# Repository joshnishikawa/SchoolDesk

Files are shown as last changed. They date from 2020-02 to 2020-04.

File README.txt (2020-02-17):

***************************************************************
     School Desk
a plug-and-play velocity-sensitive USB MIDI drum controller
***************************************************************

NOTE: School Desk is a controller. It is not a sequencer or synthesizer,
      nor is there a sound bank of any kind. It only sends MIDI messages
      to trigger sounds in a Digital Audio Workstation (DAW).
      You must have your DAW open and have School Desk assigned to control an
      instrument with its own soundbank or synthesis in the DAW.
     
Plug your School Desk into a USB port and it will be automatically recognized
as a MIDI controller and should appear as "SchoolDesk" in your DAW.

School Desk has two banks which store 11 sounds each.

These are the default sounds for Bank 1:
 __________ __________ __________ __________ __________ __________
|1         |2         |3         |4         |5         |6         |
| Crash 1  | Hi Tom   | Low Tom  | Splash   | Ride Bell| Crash 2  |
| Note #49 | Note #50 | Note #45 | Note #55 | Note #53 | Note #57 |
'----------^----------^----------^----------^----------^----------'
|7           |8           |9            |10          |11          |
| Snare Drum |  Hi-Hats   |  Floor Tom  | Ride Cymbal| Kick Drum  |
| Note #38   |  Note #46  |  Note #41   | Note #51   | Note #36   |
'------------^------------^-------------^------------^------------'

These are the default sounds for Bank 2:
 __________ __________ __________ __________ __________ __________
|1         |2         |3         |4         |5         |6         |
| Hi Timb. | Hi Bongo | Hi Conga | Cowbell  | Mute Tri.|Tambourine|
| Note #65 | Note #60 | Note #63 | Note #56 | Note #80 | Note #54 |
'----------^----------^----------^----------^----------^----------'
|7           |8           |9            |10          |11          |
| Low Timbale| Low Bongo  | Low Conga   | Triangle   | Claves     |
| Note #66   | Note #61   | Note #64    | Note #81   | Note #75   |
'------------^------------^-------------^------------^------------'

You can switch between banks 1 and 2 by quickly pressing and releasing
The "Edit" button.

--------------------------------------------------------------------------------

Different sounds can also be assigned to each pad by following these steps:

1. Press and HOLD the Edit knob on top of the controller for one second.
    (The red LED blinks when the knob is pressed and stays lit after one second)
    
2. Release the knob. The controller is now in "Program Mode" where pads can be
    assigned different sounds or be set as expression controllers.

3. While in program mode - indicated by the red LED - trigger the pad you want
    to change. The assigned sound will play (or no sound if set as expression
    controller).

4. Turn the knob until you reach the desired sound.* Turning the knob will
    reassign an expression controller as a drum sound. To assign the pad as an
    expression controller, briefly press and release the knob the same way you
    would to change between banks A and B.
    
5. When you have finished choosing your sounds. Press and hold the Edit knob
    for one second again. The LED will return to green or blue (depending on the
    bank).  The sounds you selected will be saved to internal memory and will be
    available the next time you plug in School Desk (unltil you change them).
    
    *NOTE: Turning the knob will cycle though note numbers 35 through 81.
          These are the numbers that are assigned to drum sounds according to
          the general MIDI standard. These numbers are as follows:

               GM DRUM SOUNDS
          *********************************
          MIDI# - NOTE - SOUND
            35    B  0   Acoustic Bass Drum
            36    C  1   Bass Drum 1
            37    C# 1   Side Stick
            38    D  1   Acoustic Snare
            39    D# 1   Hand Clap
            40    E  1   Electric Snare
            41    F  1   Low Floor Tom
            42    F# 1   Closed Hi Hat
            43    G  1   High Floor Tom
            44    G# 1   Pedal Hi-Hat
            45    A  1   Low Tom
            46    A# 1   Open Hi-Hat
            47    B  1   Low-Mid Tom
            48    C  2   Hi-Mid Tom
            49    C# 2   Crash Cymbal 1
            50    D  2   High Tom
            51    D# 2   Ride Cymbal 1
            52    E  2   Chinese Cymbal
            53    F  2   Ride Bell
            54    F# 2   Tambourine
            55    G  2   Splash Cymbal
            56    G# 2   Cowbell
            57    A  2   Crash Cymbal 2
            58    A# 2   Vibraslap
            59    B  2   Ride Cymbal 2
            60    C  3   Hi Bongo
            61    C# 3   Low Bongo
            62    D  3   Mute Hi Conga
            63    D# 3   Open Hi Conga
            64    E  3   Low Conga
            65    F  3   High Timbale
            66    F# 3   Low Timbale
            67    G  3   High Agogo
            68    G# 3   Low Agogo
            69    A  3   Cabasa
            70    A# 3   Maracas
            71    B  3   Short Whistle
            72    C  4   Long Whistle
            73    C# 4   Short Guiro
            74    D  4   Long Guiro
            75    D# 4   Claves
            76    E  4   Hi Wood Block
            77    F  4   Low Wood Block
            78    F# 4   Mute Cuica
            79    G  4   Open Cuica
            80    G# 4   Mute Triangle
            81    A  4   Open Triangle

    Any note which does not have a sound assigned to it in your DAW
    will not be audible.

--------------------------------------------------------------------------------

You may also set any (or all) of the pads to be used as expression controllers.

These are the Control Change numbers used for Bank 1:
 __________ __________ __________ __________ __________ __________
|1         |2         |3         |4         |5         |6         |
|          |          |          |          |          |          |
|  CC #20  |  CC #21  |  CC #22  |  CC #23  |  CC #24  |  CC #25  |
'----------^----------^----------^----------^----------^----------'
|7           |8           |9            |10          |11          |
|            |            |             |            |            |
|   CC #26   |   CC #27   |   CC #28    |   CC #29   |   CC #30   |
'------------^------------^-------------^------------^------------'

These are the Control Change numbers used for Bank 2:
 __________ __________ __________ __________ __________ __________
|1         |2         |3         |4         |5         |6         |
|          |          |          |          |          |          |
|  CC #102 |  CC #103 |  CC #104 |  CC #105 |  CC #106 |  CC #107 |
'----------^----------^----------^----------^----------^----------'
|7           |8           |9            |10          |11          |
|            |            |             |            |            |
|   CC #108  |   CC #109  |   CC #110   |   CC #111  |   CC #112  |
'------------^------------^-------------^------------^------------'

NOTE: All of these Control Change numbers are otherwise 'undefined' in the
      general MIDI specification and should therefore be safe to use.
      However, please be aware that these numbers cannot be changed.

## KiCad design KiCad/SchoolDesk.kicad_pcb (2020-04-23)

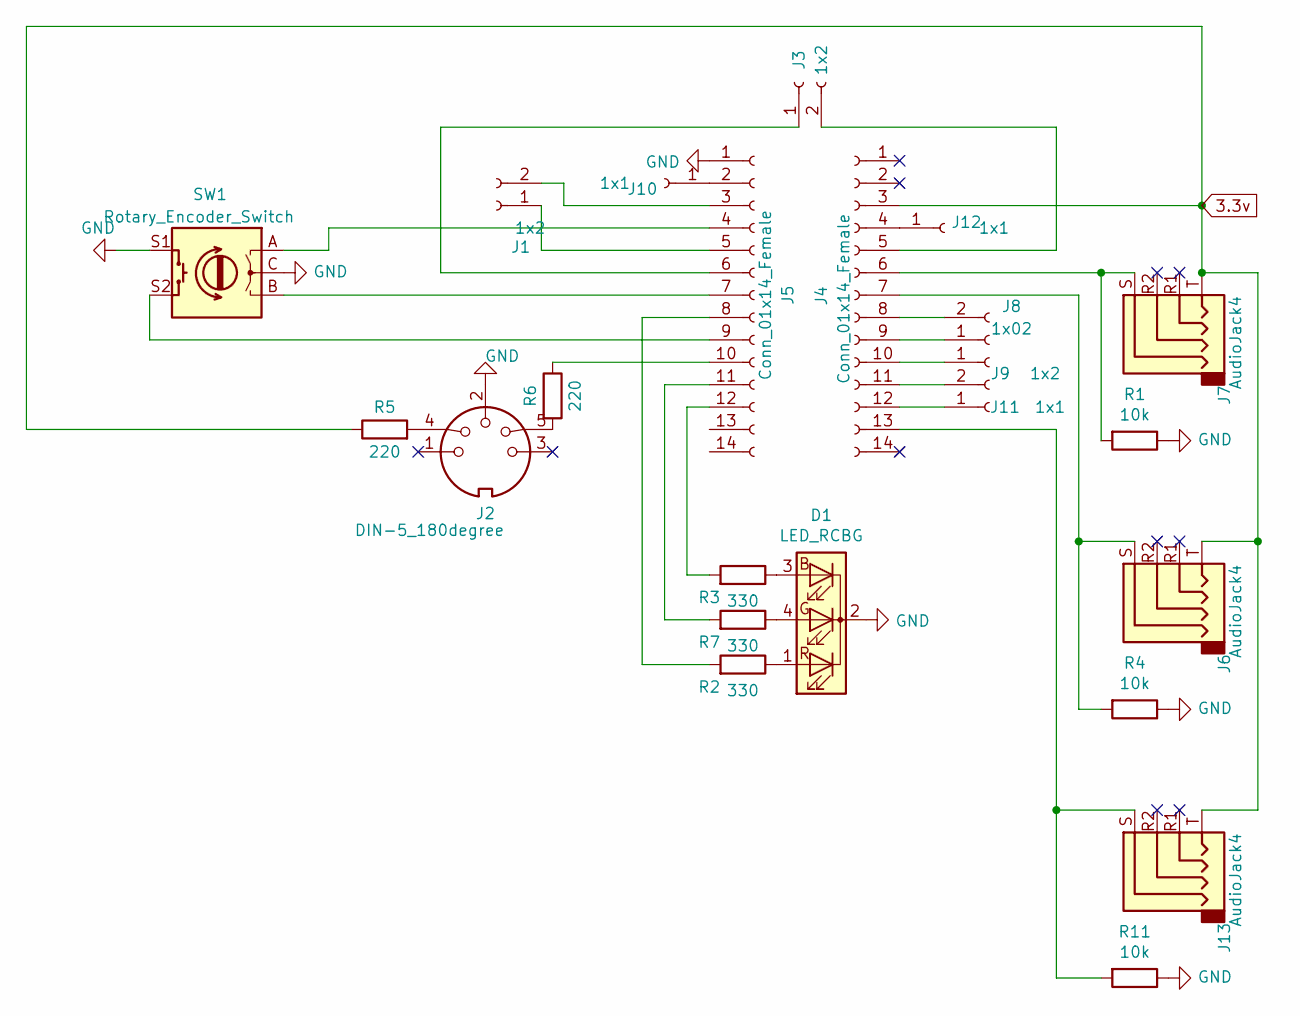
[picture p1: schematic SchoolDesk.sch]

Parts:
D1: LED_RCBG; LED_RGB_1210
J1, J3, J9: 1x2; Pin_Header_Straight_1x02_Pitch2.00mm
J2: DIN-5_180degree; SDS-50J
J4, J5: Conn_01x14_Female; PinSocket_1x14_P2.54mm_Vertical
J6, J7, J13: AudioJack4; Jack_3.5mm_PJ320D_Horizontal
J8: 1x02; Pin_Header_Straight_1x02_Pitch2.00mm
J10, J11, J12: 1x1; Pin_Header_Straight_1x01_Pitch2.00mm
R1, R4, R11: 10k; R_Axial_DIN0207_L6.3mm_D2.5mm_P2.54mm_Vertical
R2, R3, R7: 330; R_0805_2012Metric
R5, R6: 220; R_0805_2012Metric
SW1: Rotary_Encoder_Switch; Rotary_Encoder_Switched_PEC11R

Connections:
3.3v: J4.3, J6.T, J7.T, J13.T, R5.1
GND: D1.2 (K), J2.2, J5.1, R1.1, R4.1, R11.1, SW1.C, SW1.S1
unnamed: D1.1 (RA), R2.1
unnamed: D1.3 (BA), R3.1
unnamed: D1.4 (GA), R7.1
unnamed: J1.1, J5.5
unnamed: J1.2, J5.3
unnamed: J2.4, R5.2
unnamed: J2.5, R6.2
unnamed: J3.1, J5.6
unnamed: J3.2, J4.5
unnamed: J4.6, J7.S, R1.2
unnamed: J4.7, J6.S, R4.2
unnamed: J4.8, J8.2
unnamed: J4.9, J8.1
unnamed: J4.10, J9.1
unnamed: J4.11, J9.2
unnamed: J5.4, SW1.A
unnamed: J5.7, SW1.B
unnamed: J5.8, R2.2
unnamed: J5.9, SW1.S2
unnamed: J5.10, R6.1
unnamed: J5.11, R7.2
unnamed: J5.12, R3.2
unnamed: J5.2, J10.1
unnamed: J4.12, J11.1
unnamed: J4.4, J12.1
unnamed: J4.13, J13.S, R11.2

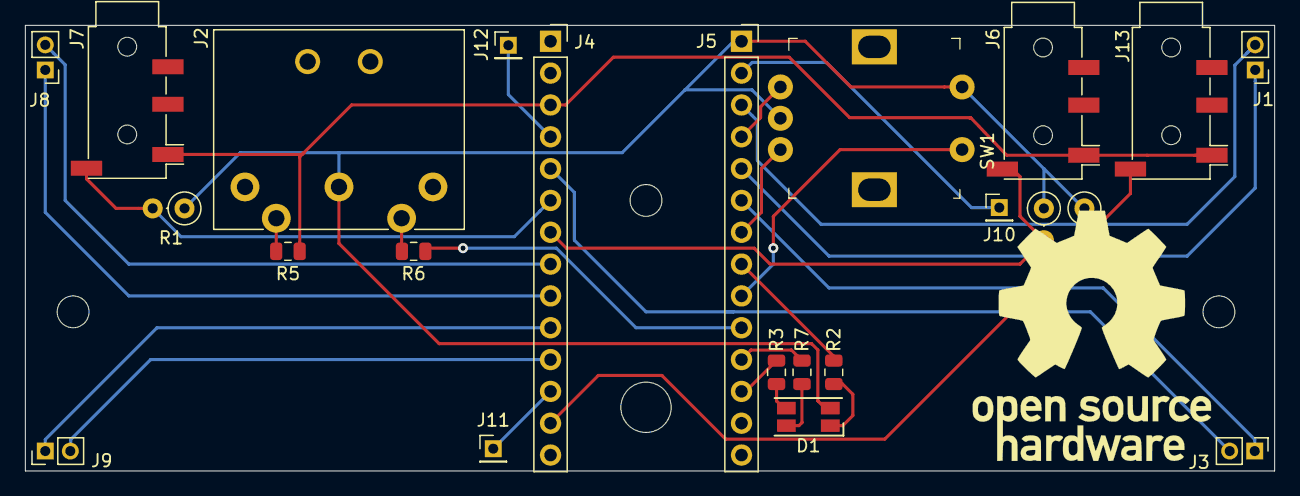
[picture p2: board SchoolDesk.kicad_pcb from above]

Board: 2 copper layers, 99.7 x 35.6 mm, 23 parts (0 on the bottom side), 28 nets.

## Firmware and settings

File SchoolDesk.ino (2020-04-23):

#include "SchoolDesk.h"

MIDI_CREATE_DEFAULT_INSTANCE();
MIDI_CREATE_INSTANCE(HardwareSerial, Serial3, MIDI1);
MIDI_CREATE_INSTANCE(HardwareSerial, Serial3, MIDI2);
MIDI_CREATE_INSTANCE(HardwareSerial, Serial3, MIDI3);

byte MIDIchannel = 10;
const int redLED = 9;
const int greenLED = 6;
const int blueLED = 10;
Editor editor = Editor(2, 5, 7);
int editMe = 255;
MIDIdrum *Drum[22]; // Drum sounds for banks A and B
MIDItouch *Exp[22]; // Exp controllers for banks A and B
bool useExp[22];    // Use Exp instead of Drum?
int bankIndex = 0;  // 0 = bank A, 11 = bank B, 
bool programMode = false;
elapsedMillis timer = 0;   // > 1000 = toggles program mode

elapsedMillis stayLit = 0; // for the metronome LED
int pulse = 0;
void onStart(){pulse = 0;}
void onContinue(){pulse = 0;}
void onStop(){pulse = 0;}

void onClock() {
  pulse = pulse == 24 ? 0 : pulse;
  if(pulse == 0){
    stayLit = 0;
    digitalWrite(LED_BUILTIN, HIGH);
  }
  pulse += 1;
}

void pulsar(){
  static int value = 0;
  static bool reverse = false;
  static elapsedMillis tempo = 0;
  int reading = Exp[editMe]->read();

  value = reading >= 0 ? reading : value;
  if (tempo >= 255 - value*2) {
    reverse = !reverse;
    tempo = 0;
  }
  analogWrite(10, reverse ? tempo*1 : 255-tempo);
}


void setup(){
  Serial.begin(9600);
  delay(1000);
  Serial.println("firstofall");
  
//  EEPROM.put(127, 255); // WARNING! RESTORES DEFAULT SETTINGS!
  byte resetDefaults = EEPROM.read(127);

  for(int i=22;i<44;i++){
    if(resetDefaults){
      useExp[i] = EEPROM.put(i, false); // Defalut to using drums only
    }
    else{useExp[i] = EEPROM.read(i);    // or load user-saved settings
    }
  }
  Serial.println("andthen");

  Drum[0]  = new MIDIdrum(19, resetDefaults ? EEPROM.put(0, 49) : EEPROM.read(0), TOUCH);
  Drum[1]  = new MIDIdrum(18, resetDefaults ? EEPROM.put(1, 50) : EEPROM.read(1), TOUCH);
  Drum[2]  = new MIDIdrum(23, resetDefaults ? EEPROM.put(2, 45) : EEPROM.read(2), TOUCH);
  Drum[3]  = new MIDIdrum( 0, resetDefaults ? EEPROM.put(3, 55) : EEPROM.read(3), TOUCH);
  Drum[4]  = new MIDIdrum( 3, resetDefaults ? EEPROM.put(4, 53) : EEPROM.read(4), TOUCH);
  Drum[5]  = new MIDIdrum( 1, resetDefaults ? EEPROM.put(5, 57) : EEPROM.read(5), TOUCH);
  Drum[6]  = new MIDIdrum(17, resetDefaults ? EEPROM.put(6, 38) : EEPROM.read(6), TOUCH);
  Drum[7]  = new MIDIdrum(16, resetDefaults ? EEPROM.put(7, 46) : EEPROM.read(7), TOUCH);
  Drum[8]  = new MIDIdrum(15, resetDefaults ? EEPROM.put(8, 41) : EEPROM.read(8), TOUCH);
  Drum[9]  = new MIDIdrum(22, resetDefaults ? EEPROM.put(9, 51) : EEPROM.read(9), TOUCH);
  Drum[10] = new MIDIdrum( 4, resetDefaults ? EEPROM.put(10,36) : EEPROM.read(10),TOUCH);

  Drum[11] = new MIDIdrum(19, resetDefaults ? EEPROM.put(11, 65) : EEPROM.read(11), TOUCH);
  Drum[12] = new MIDIdrum(18, resetDefaults ? EEPROM.put(12, 60) : EEPROM.read(12), TOUCH);
  Drum[13] = new MIDIdrum(23, resetDefaults ? EEPROM.put(13, 63) : EEPROM.read(13), TOUCH);
  Drum[14] = new MIDIdrum( 0, resetDefaults ? EEPROM.put(14, 56) : EEPROM.read(14), TOUCH);
  Drum[15] = new MIDIdrum( 3, resetDefaults ? EEPROM.put(15, 80) : EEPROM.read(15), TOUCH);
  Drum[16] = new MIDIdrum( 1, resetDefaults ? EEPROM.put(16, 54) : EEPROM.read(16), TOUCH);
  Drum[17] = new MIDIdrum(17, resetDefaults ? EEPROM.put(17, 66) : EEPROM.read(17), TOUCH);
  Drum[18] = new MIDIdrum(16, resetDefaults ? EEPROM.put(18, 61) : EEPROM.read(18), TOUCH);
  Drum[19] = new MIDIdrum(15, resetDefaults ? EEPROM.put(19, 64) : EEPROM.read(19), TOUCH);
  Drum[20] = new MIDIdrum(22, resetDefaults ? EEPROM.put(20, 81) : EEPROM.read(20), TOUCH);
  Drum[21] = new MIDIdrum( 4, resetDefaults ? EEPROM.put(21, 75) : EEPROM.read(21), TOUCH);
  Serial.println("thenwhat");

  EEPROM.put(127, 0); // Allow user settings to be saved

/*  Exp[0]  = new MIDItouch(19, 20);
  Exp[1]  = new MIDItouch(18, 21);
  Exp[2]  = new MIDItouch(23, 22);
  Serial.println("boutta");
  Exp[3]  = new MIDItouch( 0, 23);
  Exp[4]  = new MIDItouch( 3, 24);
  Exp[5]  = new MIDItouch( 1, 25);
  Exp[6]  = new MIDItouch(17, 26);
  Exp[7]  = new MIDItouch(16, 27);
  Exp[8]  = new MIDItouch(15, 28);
  Exp[9]  = new MIDItouch(22, 29);
  Exp[10] = new MIDItouch( 4, 30);

  Exp[11] = new MIDItouch(19, 102);
  Exp[12] = new MIDItouch(18, 103);
  Exp[13] = new MIDItouch(23, 104);
  Exp[14] = new MIDItouch( 0, 105);
  Exp[15] = new MIDItouch( 3, 106);
  Exp[16] = new MIDItouch( 1, 107);
  Exp[17] = new MIDItouch(17, 108);
  Exp[18] = new MIDItouch(16, 109);
  Exp[19] = new MIDItouch(15, 110);
  Exp[20] = new MIDItouch(22, 111);
  Exp[21] = new MIDItouch( 4, 112);
*/
  for(int i=0;i<22;i++){ // calibrate all drums and exp controllers
    Drum[i]->setThreshold();
//    Exp[i]->inputRange();
  }
  Serial.println("dunnit");

  pinMode(greenLED, OUTPUT);
  pinMode(redLED, OUTPUT);
  pinMode(blueLED, OUTPUT);
  pinMode(LED_BUILTIN, OUTPUT); // orangeLED

  MIDI1.begin(MIDI_CHANNEL_OMNI); //MIDI1 MIDI2 and MIDI3 only need to send
  MIDI2.begin(MIDI_CHANNEL_OMNI); //no need to read each one
  MIDI3.begin(MIDI_CHANNEL_OMNI); //or set handlers for incoming messages
  MIDI.begin(MIDI_CHANNEL_OMNI);
  MIDI.setHandleClock(onClock);
  MIDI.setHandleStart(onStart);
  MIDI.setHandleStop(onStop);
  MIDI.setHandleContinue(onContinue);
}

void loop(){
  editor.bounce->update();
  if (editor.bounce->fallingEdge()) timer = 0;

  else if (editor.bounce->risingEdge() && timer < 1000){
    if (programMode && editMe != 255){
      if (useExp[editMe]){
        useExp[editMe] = false;
        usbMIDI.sendNoteOn(Drum[editMe]->number, 63, MIDIchannel);
        usbMIDI.sendNoteOn(Drum[editMe]->number,  0, MIDIchannel);
      }
      else{useExp[editMe] = true;}
    }
    else if(!programMode){
      bankIndex = bankIndex == 11 ? 0 : 11; // toggle bank A/B
    }
  }

  else if (editor.bounce->read() == LOW){
    if (programMode && timer >= 1000){
      if (editMe != 255){
        for(int i = bankIndex; i < 11+bankIndex; i++){
          EEPROM.put(i, Drum[i]->number);
          EEPROM.put(i+22, useExp[i+22]);
        }
        editMe = 255; // no longer editing
      }
      programMode = false;
      digitalWrite(redLED, LOW);
      while (editor.bounce->read() == LOW); // wait for release
    }
    else if (!programMode && timer >= 1000){
      programMode = true;
      digitalWrite(redLED, HIGH);
      while (editor.bounce->read() == LOW);
    }
  }

  else if (programMode){/////////////////////////////////////////////////
    digitalWrite(greenLED, LOW);
    digitalWrite(blueLED, LOW);

    for(int i = bankIndex; i < 11+bankIndex; i++){
      if(useExp[i]){
        if(Exp[i]->read() > 63){
          editMe = i;
        }
      }
      else{
        if(Drum[i]->send() >= 0){
          editMe = i;
        }
      }
    }
    if(editMe != 255){
      if (useExp[editMe]){
        pulsar();
      }
      else{
        editor.setSound(Drum[editMe]->number);
      }
    }
  }

  else{//controlMode/////////////////////////////////////////////////////
    digitalWrite(greenLED, bankIndex);
    digitalWrite(blueLED, !bankIndex);

    for(int i = bankIndex; i < 11+bankIndex; i++){
        if(useExp[i]){Exp[i]->send();}
        else         {Drum[i]->send();}
    }
    editor.send(); // use encoder as MIDI CC
  }

  if(stayLit > 50){digitalWrite(LED_BUILTIN, LOW);} // metronome LED off
}

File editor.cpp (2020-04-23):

#include "editor.h"

// Editor constructors
Editor::Editor(){};

Editor::Editor(int a, int b, int p){
  pinMode(p, INPUT_PULLUP);
  bounce = new Bounce(p, 50);
  encoder = new Encoder(a, b);
  level = 0;
  editing = 0;
};

// Editor destructor
Editor::~Editor(){
  delete bounce;
  delete encoder;
};

int Editor::send(){
  int incdec = encoder->read();
  if(incdec >= 1 && level < 127){       // If turned up but not already maxed
    level += 1;
    incdec = level;
    usbMIDI.sendControlChange(9, level, MIDIchannel);
  }
  else if (incdec <= -1 && level > 0){  // If turned down but not bottomed out
    level -= 1;
    incdec = level;
    usbMIDI.sendControlChange(9, level, MIDIchannel);
  }
  else{incdec = -1;}
  encoder->write(0);
  return incdec;
};

void Editor::setSound(int sound){
  int newValue = quadOne(sound, 35, 81);
  if (newValue >= 0){
    usbMIDI.sendNoteOn(newValue, 63, MIDIchannel);
    sound = newValue;
  }
};

int Editor::quadOne(byte val, byte min, byte max){
  int newValue = encoder->read();
  if (newValue == 4){
    if (val < max){
      encoder->write(0);
      newValue = val + 1;
    }
    else if (val == max){
      encoder->write(0);
      newValue = min;
    }
  }
  else if (newValue == -4){
    if (val > min){
      encoder->write(0);
      newValue = val - 1;
    }
    else if (val == min){
      encoder->write(0);
      newValue = max;
    }
  }
  else if (newValue > 4 || newValue < -4){
    encoder->write(0);
    newValue = -1;
  }
  else{newValue = -1;}
  return newValue;
};

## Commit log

2020-01-17 Add KiCad files
    [SchoolDesk.kicad_pcb, SchoolDesk.sch]
2020-02-17 First (untested) commit including PCB files.
    [SchoolDesk-B_Cu.gbr, SchoolDesk-B_Mask.gbr, SchoolDesk-B_Paste.gbr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]
